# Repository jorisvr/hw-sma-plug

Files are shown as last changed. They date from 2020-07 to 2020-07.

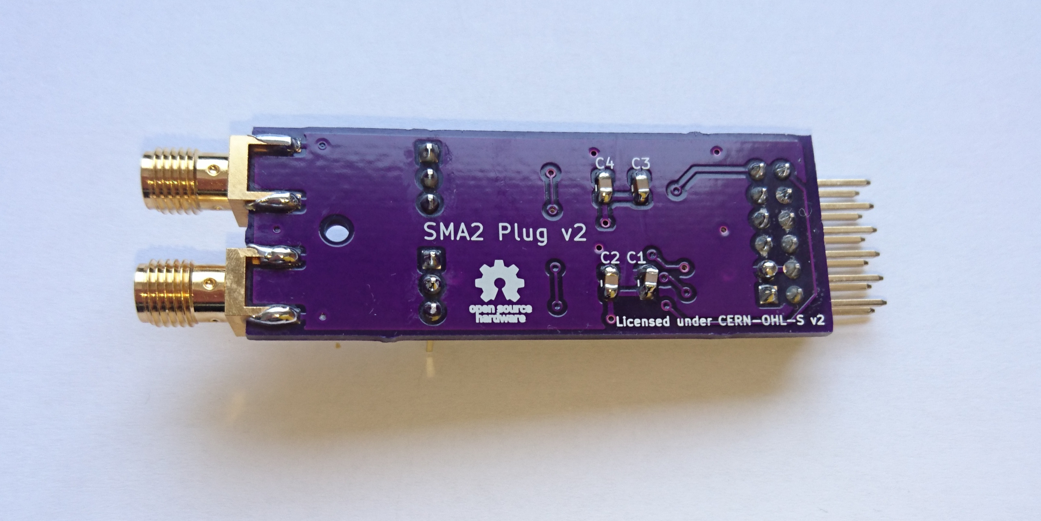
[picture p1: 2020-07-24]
sma2_plug_v2/pictures/assembled_back.jpg

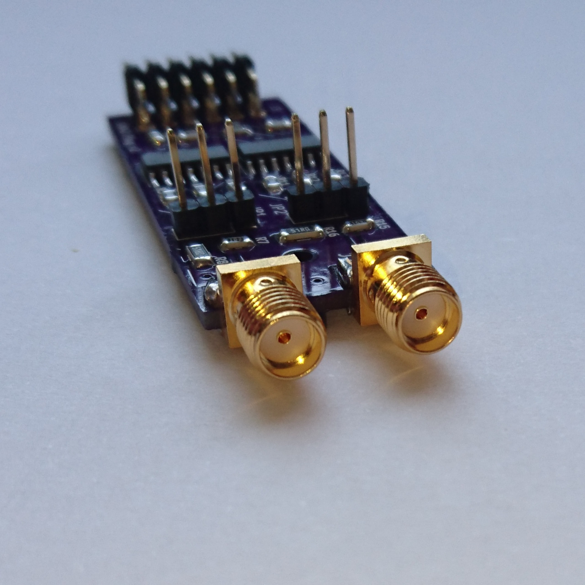
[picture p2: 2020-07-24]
sma2_plug_v2/pictures/assembled_sma_connectors.jpg

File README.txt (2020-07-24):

  SMA2 Plug v2
  ============

The SMA2 Plug is a small printed circuit board (PCB) which can
be used as an extension module to attach coaxial cables to
an FPGA board.

One side of the module has two SMA connectors which can be used
either as digital input or as digital output at TTL level.
The other side of the module has a 2x6 pin header for plugging
into an FPGA board, compatible with the Digilent Pmod specification.

For more details, see the user manual
https://github.com/jorisvr/hw-sma-plug/blob/master/sma2_plug_v2/doc/manual.pdf

The SMA2 Plug is an open hardware design. This repository contains
the complete KiCad design files and design documents for the module.

  Acknowledgements
  ----------------

Many thanks to Sidney Cadot for fundamental ideas about features
and use cases for this module and detailed discussions on the design.

Many thanks to Joris van Zwieten for reviewing the design and
for invaluable advice on SMD soldering.

  License
  -------

Copyright 2020 Joris van Rantwijk

This design documentation describes Open Hardware and is licensed
under the CERN-OHL-S v2.

You may redistribute and modify this documentation and make products
using it under the terms of the CERN-OHL-S v2
(https://cern.ch/cern-ohl).

This documentation is distributed WITHOUT ANY EXPRESS OR IMPLIED
WARRANTY, INCLUDING OF MERCHANTABILITY, SATISFACTORY QUALITY AND
FITNESS FOR A PARTICULAR PURPOSE. Please see the CERN-OHL-S v2
for applicable conditions.

Source location: https://github.com/jorisvr/hw-sma-plug

--

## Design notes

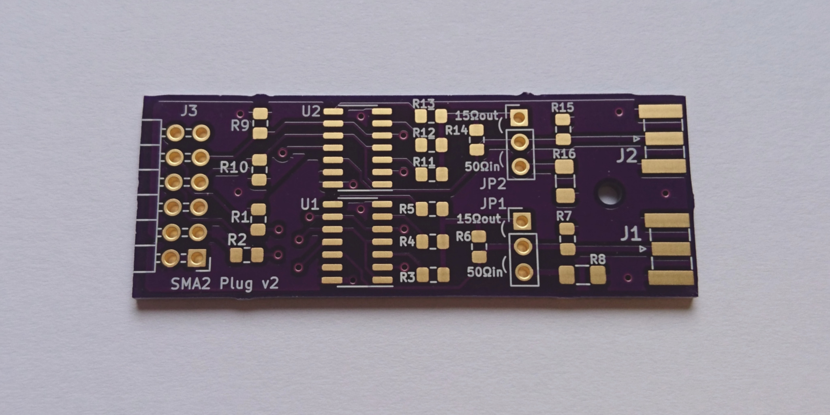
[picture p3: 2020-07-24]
sma2_plug_v2/pictures/pcb_front.jpg

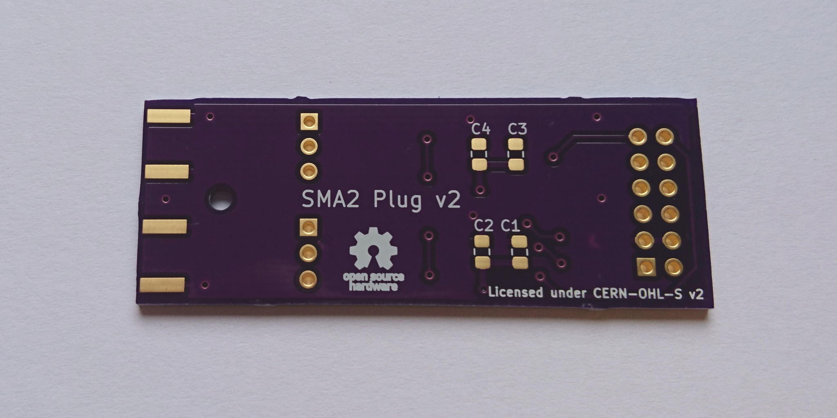
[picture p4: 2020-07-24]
sma2_plug_v2/pictures/pcb_back.jpg

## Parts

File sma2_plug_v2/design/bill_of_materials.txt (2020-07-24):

Bill of materials for SMA2 Plug v2
==================================

  qty  manufacturer + part nr          description                  package   Farnell  Conrad   refdes
  ---  ----------------------          -----------                  --------  -------  -------  ------
    2  Nexperia 74LVC126AD             quad logic buffer 74LVC126   SOIC-14   1631665           U1,U2
    2  KEMET C0805C105K3RAC            capacitor 1uF 25V X7R        0805      1637035  458056   C1,C3
    2  KEMET C0805C104J5RAC            capacitor 100nF 50V X7R      0805      1414663  458028   C2,C4
    6  Bourns CR0805-JW-103ELF         resistor 10 kOhm             0805      2008390  1055517  R1,R2,R7,R9,R10,R15
    8  Multicomp MP000066              resistor 33 Ohm 250 mW       0805      3127836           R3,R4,R5,R6,R11,R12,R13,R14
    2  Bourns CRM1206-FX-51R0ELF       resistor 51 Ohm 500 mW       1206      1865251           R8,R16
    2  Samtec SMA-J-P-H-ST-EM1         SMA connector edge-mount               2856818           J1,J2
    1  Wurth 61301221021               male pin header 2x6 angled   2.54rm    2356197  1898789  J3
    2                                  male pin header 1x3 straight 2.54rm    3226003  1581014  JP1,JP2
    2                                  jumper bridge 2.54rm                   2834673  1303885

NOTE: R8, R16 must be rated for at least 500 mW.
NOTE: R6, R14 must be rated for at least 250 mW.

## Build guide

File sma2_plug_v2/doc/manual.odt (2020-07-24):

# SMA2 Plug v2 User Manual

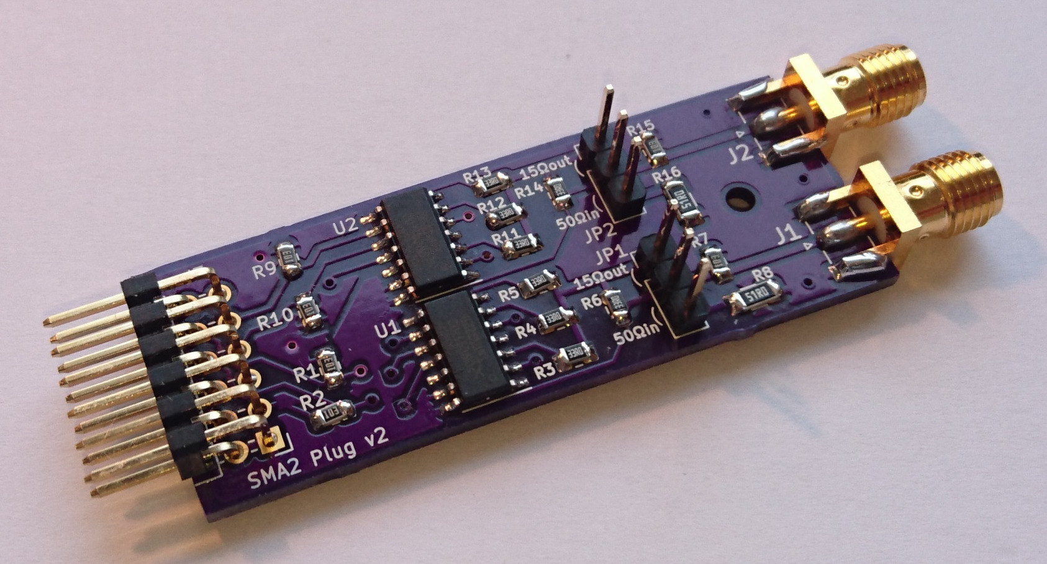
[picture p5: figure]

## Overview

The SMA2 Plug provides an easy way to connect digital TTL signals to an FPGA board via coaxial cables.

One side of the module has two SMA connectors which can each be used either as digital input or as digital output. The other side of the module has a 2x6 pin header which can be plugged into an FPGA board.

The module converts the TTL input level of each SMA connector into a matching IN signal for the FPGA. The module also expects two output signals from the FPGA for each SMA connector: OE (output enable) to enable or disable the output function, and OUT to determines whether the output (if enabled) produces a logic high or logic low level.

Features:

- Two SMA connectors for external digital signals, separately configurable as input or output.
- Useful for connecting TTL control signals or trigger signals to external equipment.
- Signal rate up to 100 Mbit/s.
- Input impedance 10 kOhm or 50 Ohm, configurable via jumper.
- Output 3.3 Volt with 50 Ohm output impedance into high impedance load, or 2.5 Volt with low output impedance into 50 Ohm load, configurable via jumper.
- Compatible with Digilent Pmod specification.

See https://github.com/jorisvr/hw-sma-plug for schematics and design files.

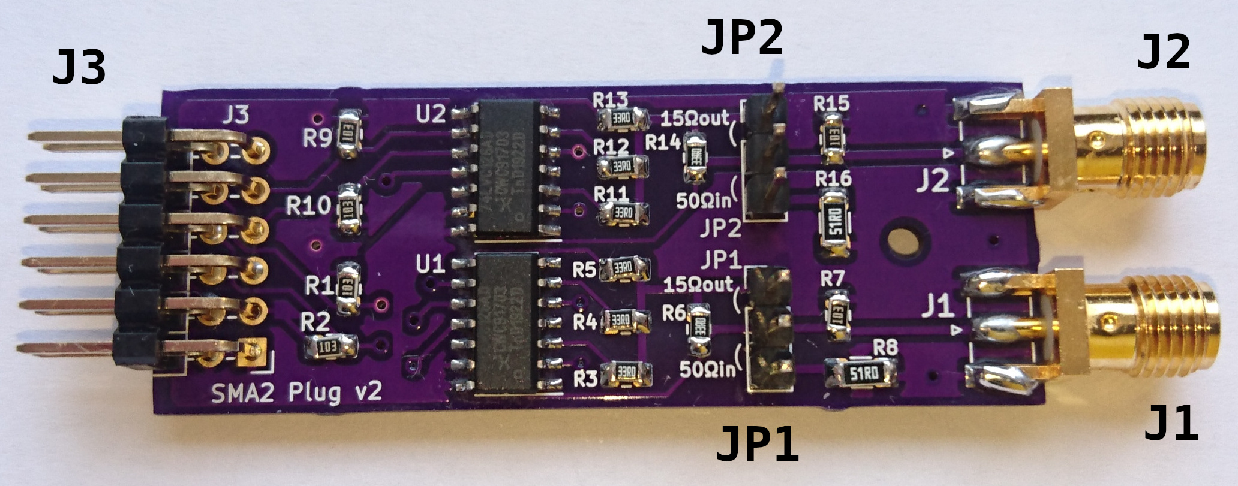
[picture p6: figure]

## Connectors

Label | Type | Description
J1 | SMA | Digital input/output channel 1
J2 | SMA | Digital input/output channel 2
J3 | 2x6 pin header | Connection to FPGA board

Table 1: Connectors

Connector J3 is compatible with the Digilent Pmod specification v1.2.0

(see https://reference.digilentinc.com/reference/pmod/start). This means the module will work when plugged into a dual-row Pmod connector as present on many Digilent FPGA boards.

Figure 1: Pin numbers of Pmod connector on host FPGA board and SMA Plug module

host Pmod socket

host board edge

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
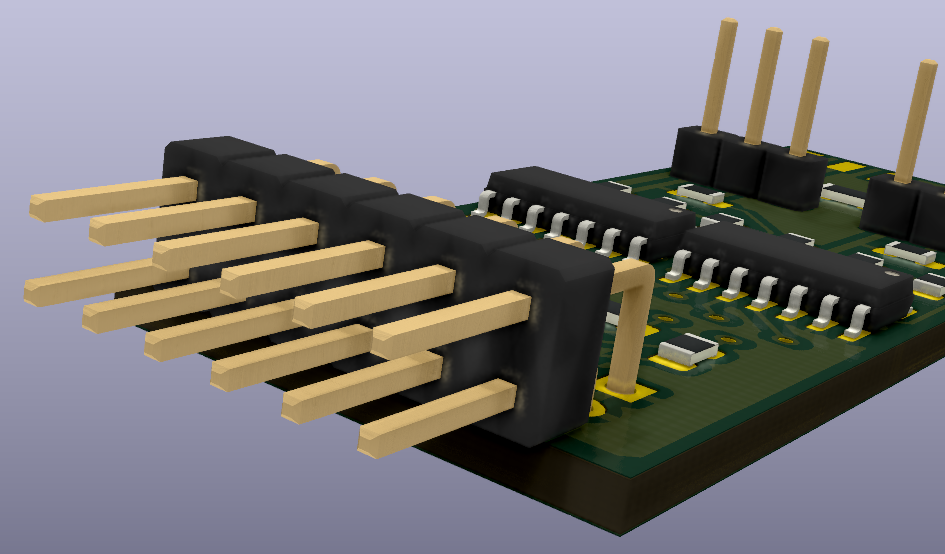
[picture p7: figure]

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
The pin functions of connector J3 match Pmod interface type 1A (GPIO).

The pin assignments are as follows:

Pin nr | Name | In/out | Function
1 | IN2 | FPGA input | Input signal from J2.
2 | OUT2 | FPGA output | Output signal for J2.
3 | OE2 | FPGA output | High to enable output via J2; low to disable output via J2.
4 | | | not connected
5 | GND | | 0 V ground
6 | 3V3 | | +3.3 V power supply from FPGA board
7 | IN1 | FPGA input | Input signal from J1.
8 | OUT1 | FPGA output | Output signal for J1.
9 | OE1 | FPGA output | High to enable output via J1; low to disable output via J1.
10 | | | not connected
11 | GND | | 0 V ground
12 | 3V3 | | +3.3 V power supply from FPGA board

Table 2: Connector J3 pin assignments

Note: These pin number assignments are based on the Digilent Pmod specification. The schematic of the SMA2 Plug v2 uses different pin numbers internally.

## Jumpers

Each of the two SMA ports has a 3-pin jumper which is used to choose between 3 modes of operation for that port. The jumper settings are as follows:

Jumper not connected

1

2

3

15Ω out

50Ω in

This is the best setting to use in most cases.

The input function receives a TTL signal from an external device. The SMA Plug input has 10 kΩ termination. The external device is expected to provide 50 Ω source termination to avoid reflections in the cable.

The output function drives a 3.3 V TTL signal to an external device with high input impedance. The output has 50 Ω series termination to avoid reflections in the coax cable. The external device must have high input impedance (at least 500 Ω) to ensure that the output meets the TTL threshold.

Input function: 10 kΩ input impedance.

Input threshold: logic low level max 0.8 V, logic high level min 2.0 V.

Output function: 50 Ω output resistance.

Output levels: 0.0 V to 3.2 V into high-impedance load.

Jumper connected from pin 1 to pin 2

1

2

3

15Ω out

50Ω in

This mode is suitable for driving a 2.5 V TTL output signal to an external device with 50 Ω input impedance.

The jumper reduces the output resistance of the SMA Plug to 15 Ω to make it strong enough to drive a 50 Ω load. This only works well if the coax cable ends in 50 Ω termination at the external device, otherwise reflections may occur.

Input function: 10 kΩ input impedance.

Input threshold: logic low level max 0.8 V, logic high level min 2.0 V.

Output function: 15 Ω output resistance.

Output levels: 0.0 V to 2.5 V into 50 Ω load.

Jumper connected from pin 2 to pin 3

1

2

3

15Ω out

50Ω in

This mode is suitable for TTL input from an external device which is designed to drive a 50 Ω load. The jumper connects a 50 Ω load resistor between the SMA port and ground to terminate the coax cable.

In this mode the input voltage must stay below 3.6 V to prevent overheating of the load resistor.

Input function: 50 Ohm input impedance.

Input threshold: logic low level max 0.8 V, logic high level min 2.0 V.

Output function: not usable (keep OEn = '0').

## Specifications

Physical specifications

Board dimensions: | 54.4 x 20.4 mm

Damage limits

Input voltage limits: | minimum | −0.5 V
| maximum (10 kΩ input impedance) | +5.5 V
| maximum (50 Ω input impedance) | +3.6 V
Output load: | minimum load resistance | 30 Ω

Exceeding these limits may damage the SMA Plug.

Short-circuiting the SMA connector with output enabled may damage the SMA Plug.

Voltage levels

Input thresholds: | logic low level, maximum input voltage | 0.8 V
| logic high level, minimum input voltage | 2.0 V
Output levels: (typical) | logic low output level | 0.0 V
| logic high output level (50 Ω output resistance, > 1 kΩ load) | 3.2 V
| logic high output level (15 Ω output resistance, 50 Ω load) | 2.5 V

Power consumption

Supply current: (typical) | both outputs disabled | 1 mA
| both outputs enabled, logic high output, 15 Ω output resistance, 50 Ω load | 100 mA

Copyright 2020 Joris van Rantwijk

This manual describes Open Hardware and is licensed under the CERN-OHL-S v2.

You may redistribute and modify this documentation and make products using it under the terms of the CERN-OHL-S v2 (https://cern.ch/cern-ohl).

This documentation is distributed WITHOUT ANY EXPRESS OR IMPLIED WARRANTY, INCLUDING OF MERCHANTABILITY, SATISFACTORY QUALITY AND FITNESS FOR A PARTICULAR PURPOSE. Please see the CERN-OHL-S v2 for applicable conditions.

Source location: https://github.com/jorisvr/hw-sma-plug

SMA2 Plug v2 User Manual 20200718 4 / 4

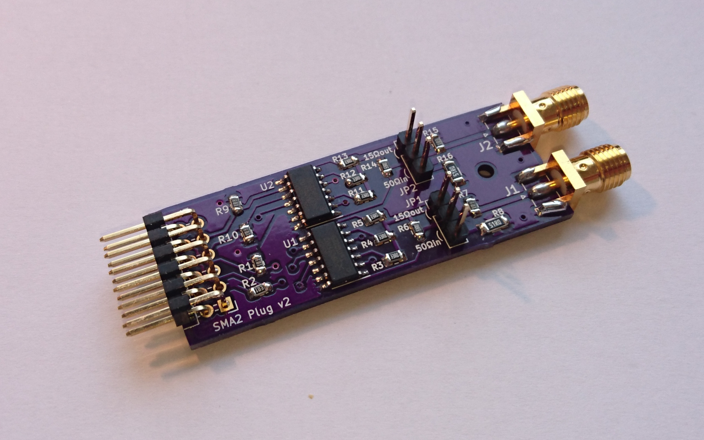
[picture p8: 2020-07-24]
sma2_plug_v2/pictures/assembled_front_angle.jpg

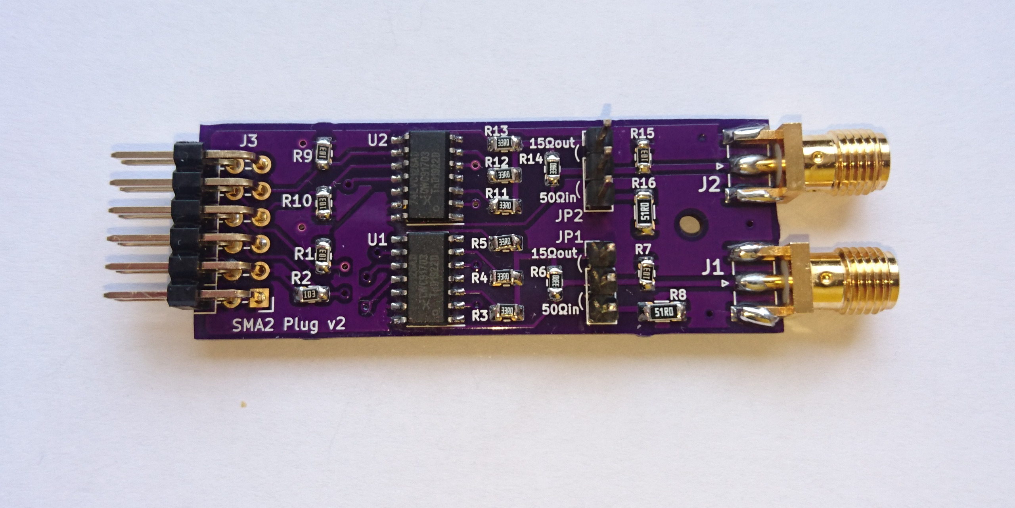
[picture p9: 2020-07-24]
sma2_plug_v2/pictures/assembled_front.jpg

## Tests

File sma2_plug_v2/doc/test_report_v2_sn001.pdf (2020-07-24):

## Test Report: SMA2 Plug v2 nr 001

Design: | SMA2 Plug v2
Serial number: | 001
Date tested: | 2020-07-23
Tested by: | joris
Report date: | 2020-07-23

## Pmod pinout

This test report refers to Pmod pins according to the non-standard pin number assignments used in the Digilent Pmod specification.

Looking away from the peripheral board, into the Pmod connector on the host board, the pin numbers are as follows:

The SMA2_Plug_v2 board uses the pinout of Digilent Pmod Interface Type 1 (GPIO).

Pin nr | function | in/out
1 | IN2 | output from peripheral
2 | OUT2 | input to peripheral
3 | OE2 | input to peripheral
7 | IN1 | output from peripheral
8 | OUT1 | input to peripheral
9 | OE1 | input to peripheral
4, 10 | not connected
5, 11 | GND
6, 12 | +3.3 V
Test Report - SMA2_Plug_v2 nr 001 | 1
6 | 5 | 4 | 3 | 2 | 1
12 | 11 | 10 | 9 | 8 | 7

host Pmod socket

host board edge

### Sanity checks

1.1. Remove jumpers JP1 and JP2 (to select 50 Ω output resistance).
1.2. Use a multimeter to measure the resistance between Pmod pins 5 and 11.
1.3. Use a multimeter to measure the resistance between Pmod pins 6 and 12.
Measurement | Expected | Result
1.2. Pmod pin 5 to pin 11 | < 0.1 Ω | 0.0 Ω OK
1.3. Pmod pin 6 to pin 12 | < 0.1 Ω | 0.0 Ω OK
1.4. Use a multimeter to measure the resistance between Pmod pin 5 and the shell of SMA connector J1.
1.5. Use a multimeter to measure the resistance between Pmod pin 5 and the shell of SMA connector J2.
Measurement | Expected | Result
1.3. Pmod pin 5 to J1 shell | < 0.1 Ω | 0.0 Ω OK
1.4. Pmod pin 5 to J2 shell | < 0.1 Ω | 0.0 Ω OK
1.6. Set a DC voltage source to +3.3 V, limited to 100 mA.
Connect the negative supply terminal to pin 5.
Connect the positive supply terminal to pin 6.
Leave the other Pmod pins unconnected.
1.7. Use a multimeter to measure the supply voltage.
1.8. Use a multimeter to measure the supply current.
1.9. Additionally connect Pmod pin 9 (OE1) to +3.3 V and measure the supply current.
1.10. Connect both Pmod pin 8 (OUT1) and Pmod pin 9 (OE1) to +3.3 V and measure the supply current.
1.11. Disconnect Pmod pins 8 and 9.
Connect Pmod pin 3 (OE2) to +3.3 V and measure the supply current.
1.12. Connect both Pmod pin 2 (OUT2) and Pmod pin 3 (OE2) to +3.3 V and measure the supply current.
Measurement | Expected | Result
1.7. Supply voltage | min 3.2 V, max 3.4 V | 3.30 V OK
1.8. Supply current | < 1 mA | 0.0 mA OK
1.9. Supply current, OE1=+3.3V | < 3 mA | 0.3 mA OK
1.10. Supply current, OE1=OUT1=+3.3V | < 3 mA | 1.0 mA OK
1.11. Supply current, OE2=+3.3V | < 3 mA | 0.3 mA OK
1.12. Supply current, OE2=OUT2=+3.3V | < 3 mA | 1.0 mA OK
1.13. Disconnect Pmod pins 2 and 3. Disconnect the power supply.
Test Report - SMA2_Plug_v2 nr 001 | 2

### Functional test

2.1. Remove jumpers JP1 and JP2 (to select 50 Ω output resistance).
Attach the SMA2 Plug to a Pmod type 1 (GPIO) connector on a suitable Digilent host board (for example Basys or Atlys).
Make sure the Pmod connector on the host board is configured for 3.3 Volt operation.
2.2. Program the host board to drive logic '0' to OUT1, OE1, OUT2, OE2.
2.3. Use the host board to read the logic levels from IN1, IN2.
2.4. Connect a +3.3 Volt input signal to SMA connector J1.
Use the host board to read the logic levels from IN1, IN2.
2.5. Disconnect the input signal from J1.
Connect a +3.3 Volt input signal to SMA connector J2.
Use the host board to read the logic levels from IN1, IN2.
Measurement | Expected | Result
2.3. Input not connected | IN1=0, IN2=0 | OK
2.4. J1 = 3.3 V | IN1=1, IN2=0 | OK
2.5. J2 = 3.3 V | IN1=0, IN2=1 | OK
2.6. Disconnect the input signal from J2.
Connect a multimeter to measure the output voltage from J1.
Use the host board to drive the following logic patterns and measure the output voltage from J1 for each pattern.
Measurement | Expected | Result
OUT1=0, OE1=0, OUT2=0, OE2=0 | J1 ≥ 0.0 V, J1 < 0.2 V | 0.00 V OK
OUT1=0, OE1=0, OUT2=1, OE2=1 | J1 ≥ 0.0 V, J1 < 0.2 V | 0.00 V OK
OUT1=1, OE1=0, OUT2=0, OE2=0 | J1 ≥ 0.0 V, J1 < 0.2 V | 0.00 V OK
OUT1=0, OE1=1, OUT2=0, OE2=0 | J1 ≥ 0.0 V, J1 < 0.2 V | 0.00 V OK
OUT1=1, OE1=1, OUT2=0, OE2=0 | J1 > 3.1 V, J1 < 3.4 V | 3.26 V OK
2.7. Disconnect the input signal from J1.
Connect a multimeter to measure the output voltage from J2.
Use the host board to drive the following logic patterns and measure the output voltage from J2 for each pattern.
Measurement | Expected | Result
OUT1=0, OE1=0, OUT2=0, OE2=0 | J2 ≥ 0.0 V, J2 < 0.2 V | 0.00 V OK
OUT1=1, OE1=1, OUT2=0, OE2=0 | J2 ≥ 0.0 V, J2 < 0.2 V | 0.00 V OK
OUT1=0, OE1=0, OUT2=1, OE2=0 | J2 ≥ 0.0 V, J2 < 0.2 V | 0.00 V OK
OUT1=0, OE1=0, OUT2=0, OE2=1 | J2 ≥ 0.0 V, J2 < 0.2 V | 0.00 V OK
OUT1=0, OE1=0, OUT2=1, OE2=1 | J2 > 3.1 V, J2 < 3.4 V | 3.26 V OK
Test Report - SMA2_Plug_v2 nr 001 | 3

2.8. Use the host board to drive OE1 = 1, OUT1 = 1, OE2 = 1, OUT2 = 1.
Use a multimeter to measure the output voltage from J1 and J2.
Then connect a 50 Ohm resistor in parallel to the multimeter (use an SMA T-joint). Again measure the output voltage from J1 and J2.
Measurement | Expected | Result J1 | Result J2
high output level, high-Z | > 3.1 V, < 3.4 V | 3.257 V | 3.257 V
high output level, 50 Ohm | > 1.5 V, < 1.7 V | 1.648 V | 1.656 V
2.9. Place jumpers JP1 and JP2 in the "15 Ω output" position.
Use the host board to drive OE1 = 1, OUT1 = 1, OE2 = 1, OUT2 = 1.
Use a multimeter to measure the output voltage from J1 and J2.
Then connect a 50 Ohm resistor in parallel to the multimeter (use an SMA T-joint). Again measure the output voltage from J1 and J2.
Measurement | Expected | Result J1 | Result J2
high output level, high-Z | > 3.1 V, < 3.4 V | 3.268 V | 3.268 V
high output level, 50 Ohm | > 2.4 V, < 2.6 V | 2.474 V | 2.480 V
2.10. Remove jumpers JP1 and JP2.
Use the host board to drive OE1 = 0, OUT1 = 0, OE2 = 0, OUT2 = 0.

Use a multimeter to measure the input resistance of J1 and J2.
Then place jumpers JP1 and JP2 in the "50 Ω input" position.
Again measure the input resistance of J1 and J2.
Measurement | Expected | Result J1 | Result J2
input resistance, high-Z | > 9 kΩ , < 11 kΩ | 10.00 kΩ | 10.00 kΩ
input resistance, 50 Ohm | > 48 Ω, < 52 Ω | 50.8 Ω | 50.8 Ω
Test Report - SMA2_Plug_v2 nr 001 | 4

### Input performance test

3.1. Remove jumpers JP1 and JP2.
Attach the SMA2 Plug to a Pmod type 1 (GPIO) connector on a suitable Digilent host board (for example Basys or Atlys).
3.2. Connect a signal generator to SMA connector J1.
Usa an SMA T-joint to also measure the voltage with a multimeter.

Configure the signal generator for high-Z load.
Set the signal generator to 0.0 Volt DC output.
Use the host board to check that the IN1 logic level is '0'.
3.3. Slowly tune up the DC output voltage from 0.0 Volt to +3.3 Volt.
Verify that the multimeter follows the configured output voltage.

While tuning up the input voltage, monitor the IN1 logic level with the host board. Note the voltage where the IN1 logic level changes from '0' to '1'.
Then tune down the input voltage and note where IN1 changes from '1' to '0'.
Measurement | Expected | Result J1 | Result J2
3.2. Jx = 0.0 V | INx=0 | OK | OK
3.3. 0-to-1 threshold | > 0.8 V, < 2.0 V | 1.70 V | 1.69 V
3.3. 1-to-0 threshold | > 0.8 V, < 2.0 V | 1.64 V | 1.64 V
3.4. Set the signal generator to +3.3 Volt DC output.
Check that the multimeter shows +3.3 Volt.
3.5. Place jumper JP1 in the "50 Ω input" position. Configure the signal generator for 50 Ohm load. Set the signal generator to +3.3 Volt DC output.
Check that the multimeter shows +3.3 Volt.
Check that the IN1 logic level is '1'.
Measurement | Expected | Result J1 | Result J2
3.4. voltage at +3.3V, high-Z | > 3.2 V, < 3.4 V | 3.273 V | 3.274 V
3.5. voltage at +3.3 V, 50 Ohm | > 3.2 V, < 3.4 V | 3.322 V | 3.324 V
3.5. INx at +3.3 V, 50 Ohm | INx=1 | OK | OK
Test Report - SMA2_Plug_v2 nr 001 | 5

3.6. Remove the T-joint and multimeter.
Connect the signal generator directly to J1, using a coax cable of at least 10 m length.

Leave jumper JP1 in the "50 Ω input" position.
Configure the signal generator for 50 Ohm load.
Set the signal generator to square wave output, 1 MHz, 50% duty cycle, 0.0 Volt to +2.5 Volt (2.5 Vpp with +1.25 V offset).

Use the host board to sample the IN1 signal at a sample rate of 500 MS/s.
Record the min/max/avg pulse high duration and the min/max/avg pulse low duration.

Calculate the square wave frequency from the average pulse durations:
freq = 1 / (avg_pulse_low + avg_pulse_high)

Calculate the duty cycle from the average pulse lengths:
duty_cycle = avg_pulse_high / (avg_pulse_low + avg_pulse_high)

Calculate the peak-to-peak jitter:
jitter = max(max_pulse_high - min_pulse_high, max_pulse_low - min_pulse_low)
Measurement | Expected | Result J1 | Result J2
pulse low: min/max/avg (ns) | | 500 / 504 / 501.9 | 500 / 504 / 502.0
pulse high: min/max/avg (ns) | | 496 / 500 / 498.1 | 496 / 500 / 498.0
frequency | 1 MHz +/- 0.01 MHz | 1.000 MHz | 1.000 MHz
duty cycle | > 49%, < 51% | 50.2 % | 50.2 %
jitter | < 5 ns | 4 ns | 4 ns
3.7. Configure the signal generator for high-Z load.
Set the signal generator to 1 MHz square wave output, 0.0 Volt to +2.5 Volt. Remove jumper JP1.
Repeat the measurements of 3.6., this time in high-Z configuration.
Measurement | Expected | Result J1 | Result J2
pulse low: min/max/avg (ns) | | 500 / 504 / 502.0 | 500 / 504 / 502.0
pulse high: min/max/avg (ns) | | 496 / 500 / 498.0 | 496 / 500 / 498.0
frequency | 1 MHz +/- 0.01 MHz | 1.000 MHz | 1.000 MHz
duty cycle | > 49%, < 51% | 50.2 % | 50.2 %
jitter | < 5ns | 4 ns | 4 ns
3.8. Use the host board to generate cross-talk on the other channel:
Set OE2 = '1' and send a random sequence of bits to OUT2 at 100 Mbit/s. Repeat the jitter measurements of step 3.7 under these conditions.
Measurement | Expected | Result J1 | Result J2
jitter | < 5ns | 4 ns | 4 ns
3.9. Disconnect the signal generator from J1.
Repeat steps 3.2. to 3.8. but this time use input J2, jumper J2, monitor IN2 and generate cross-talk through OE1, OUT1.
Test Report - SMA2_Plug_v2 nr 001 | 6

### Output performance test

4.1. Remove jumpers JP1 and JP2 to select 50 Ω output resistance.
Attach the SMA2 Plug to a Pmod type 1 (GPIO) connector on a suitable Digilent host board (for example Basys or Atlys).
4.2. Connect SMA connector J1 to an oscilloscope with at least 200 MHz analog bandwidth. Use a coax cable of at most 2 m length.
Set the scope to DC coupling, 1 MOhm input impedance, full bandwidth.
4.3. Set the host board to drive OE1 = 1, OUT1 = 0, OE2 = 0, OUT2 = 0.
Analyze the J1 waveform on the scope.
It should be a DC voltage. Note mean level and noise.
4.4. Set the host board to drive OE1 = 1, OUT1 = 0, OE2 = 1 and send a random sequence of bits to OUT2 at 100 Mbit/s.
Analyze the J1 noise on the scope.
4.5. Set the host board to drive OE1 = 1, OUT1 = 1, OE2 = 0, OUT2 = 0.
Analyze the J1 waveform on the scope.
It should be a DC voltage. Note mean level and noise.
4.6. Set the host board to drive OE1 = 1, OUT1 = 1, OE2 = 1 and send a random sequence of bits to OUT2 at 100 Mbit/s.
Analyze the J1 noise on the scope.
Measurement | Expected | Result J1 | Result J2
4.3. mean output signal | ≥ 0.0 V, < 0.2 V | 0.0 V
4.3. noise (other channel silent) | < 0.2 V pp | 0.03 V pp
4.4. noise (other channel busy) | < 0.2 V pp | 0.03 V pp
4.5. mean output signal | > 3.1 V, < 3.4 V | 3.24 V
4.5. noise (other channel silent) | < 0.2 V pp | 0.02 V pp
4.6. noise (other channel busy) | < 0.2 V pp | 0.02 V pp
Test Report - SMA2_Plug_v2 nr 001 | 7

4.7. Set the host board to drive OE1 = 1, OE2 = 0, OUT2 = 0 and drive a 1 MHz square wave to OUT1.
Analyze the J1 waveform on the oscilloscope.
It should be a 1 MHz square wave. Note the mean high and low levels.
Note the rise time and fall time. Note the overshoot.
Note the interval between successive rising edges.
Note the peak-to-peak jitter: the interval between longest and shortest period (use the persistent display mode of the scope).
Measurement | Expected | Result J1 | Result J2
mean low level | > −0.1 V, < 0.2 V | 0.02 V
mean high level | > 3.1 V, < 3.4 V | 3.22 V
rise time from 0.8 V to 2.0 V | < 5 ns | < 1 ns
fall time from 2.0 V to 0.8 V | < 5 ns | < 1 ns
rising edge overshoot | < 0.2 V | 0.20 V
falling edge overshoot | < 0.2 V | 0.16 V
no ringing (repeated overshoot) | | OK
period | 1 μs ± 10 ns | 1.000 us
jitter | < 5 ns pp | < 1 ns pp

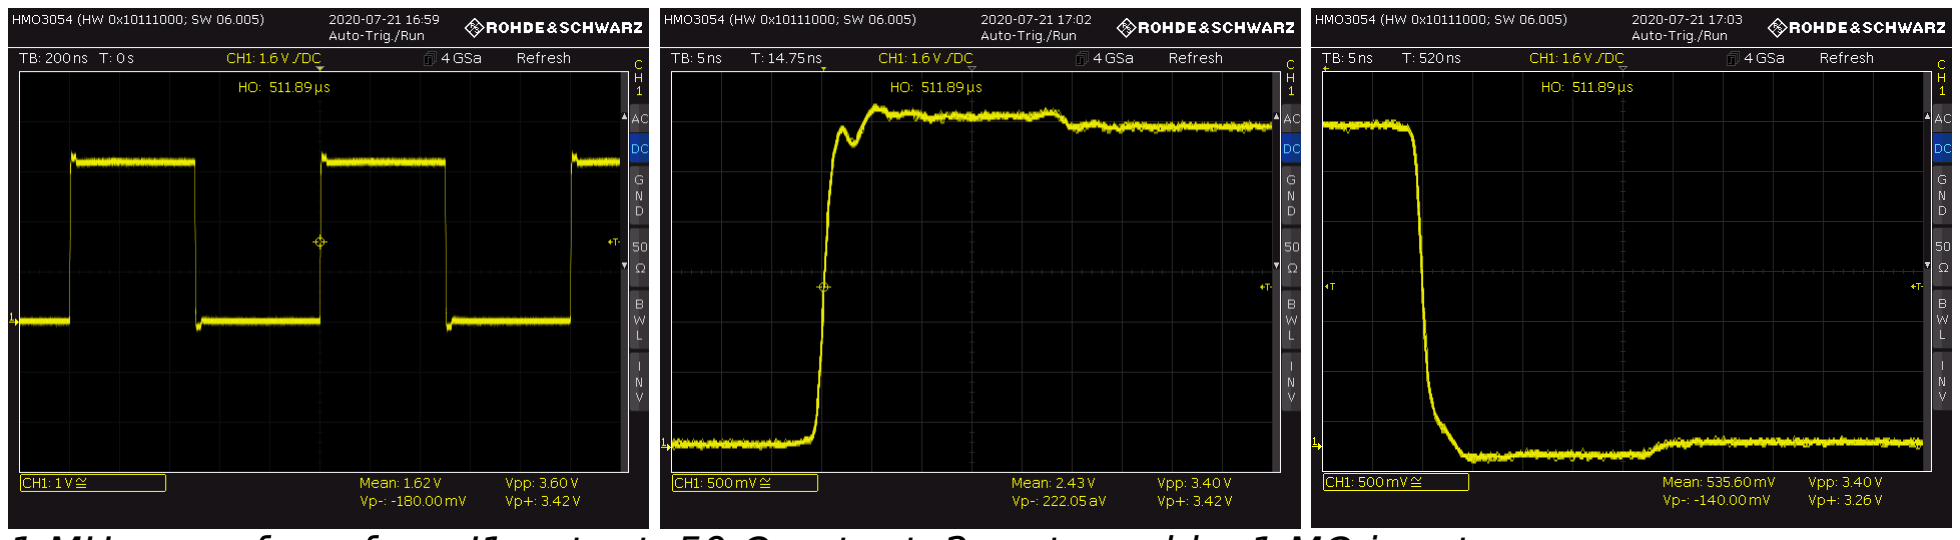
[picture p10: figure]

1 MHz waveform from J1 output, 50 Ω output, 2 meter cable, 1 MΩ input on scope

4.8. Reconnect the oscilloscope to J1 using a coax cable of at least 10 m length. Repeat the measurement of 4.7.
Measurement | Expected | Result J1 | Result J2
mean low level | > −0.1 V, < 0.2 V | 0.02 V | 0.03 V
mean high level | > 3.1 V, < 3.4 V | 3.23 V | 3.22 V
rise time from 0.8 V to 2.0 V | < 5 ns | 1 ns | 1 ns
fall time from 2.0 V to 0.8 V | < 5 ns | < 2 ns | < 2 ns
rising edge overshoot | < 0.2 V | 0.18 V | 0.18 V
falling edge overshoot | < 0.2 V | 0.17 V | 0.18 V
no ringing (repeated overshoot) | | OK | OK
jitter | < 5 ns pp | < 1 ns pp | < 1 ns pp
Test Report - SMA2_Plug_v2 nr 001 | 8

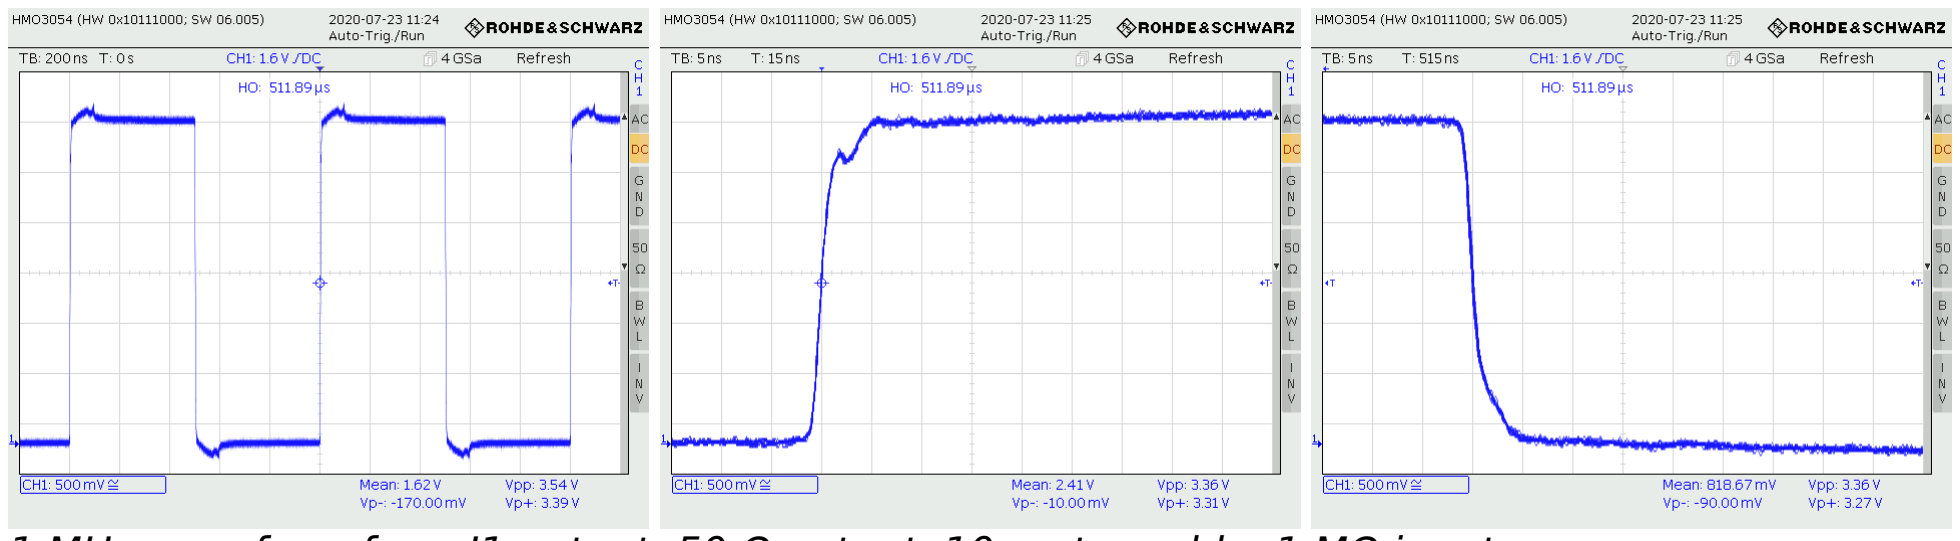
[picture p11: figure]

1 MHz waveform from J1 output, 50 Ω output, 10 meter cable, 1 MΩ input on scope

4.9. Set the host board to drive OE = 1, OE2 = 1, drive a 1 MHz square wave to OUT1, and send a random sequence of bits to OUT2 at 100 Mbit/s.
Check the jitter on the oscilloscope.
Measurement | Expected | Result J1 | Result J2
jitter | < 5 ns pp | < 1 ns pp | < 1 ns pp
4.10. Set the host board to drive OE1 = 1, OE2 = 1 and send independent random sequences of bits to OUT1 and OUT2 at 100 Mbit/s.
Set the oscilloscope time base to 5 ns.
Trigger on rising edge with trigger level +1.4 V.
Enable persistence and collect at least 10000 traces.

Analyze the resulting eye pattern. Note the duration of the interval where the signal is either below +0.8 V or above +2.0 V in each collected trace.

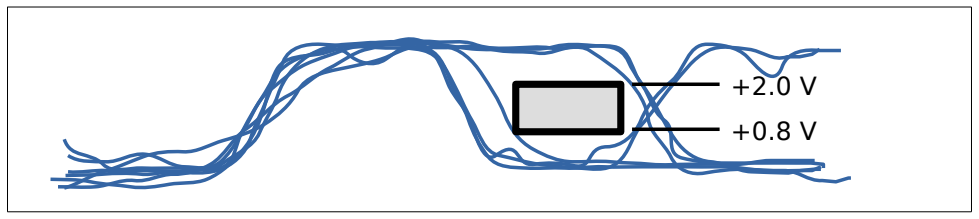
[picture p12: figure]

Measurement | Expected | Result J1 | Result J2
eye pattern clear duration | > 5 ns | 7 ns | 7 ns

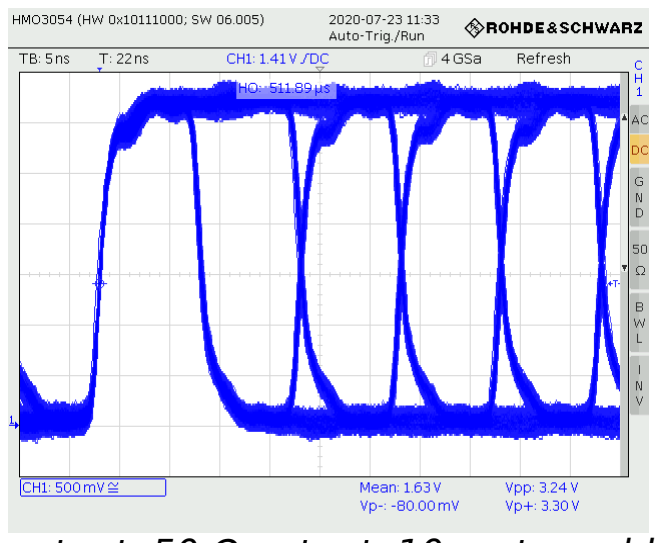
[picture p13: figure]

100 Mbit random data from J1 output, 50 Ω output, 10 meter cable, 1 MΩ input on scope

Test Report - SMA2_Plug_v2 nr 001 | 9

4.11. Switch the oscilloscope to 50 Ω input.
Place jumpers JP1 and JP2 in the "15 Ω output" position.
Repeat the measurements of 4.8, 4.9 and 4.10.

1 MHz square signal, other channel silent, 10 m cable, 15 Ω output, 50 Ω scope:
Measurement | Expected | Result J1 | Result J2
mean low level | > −0.1 V, < 0.2 V | 0.02 V | 0.03 V
mean high level | > 2.4 V, < 2.6 V | 2.42 V | 2.42 V
rise time from 0.8 V to 2.0 V | < 5 ns | 1 ns | 1 ns
fall time from 2.0 V to 0.8 V | < 5 ns | 1 ns | 1 ns
rising edge overshoot | < 0.2 V | 0.0 V | 0.0 V
falling edge overshoot | < 0.2 V | 0.0 V | 0.0 V
no ringing (repeated overshoot) | | OK | OK
jitter | < 5 ns pp | < 1 ns pp | < 1 ns pp

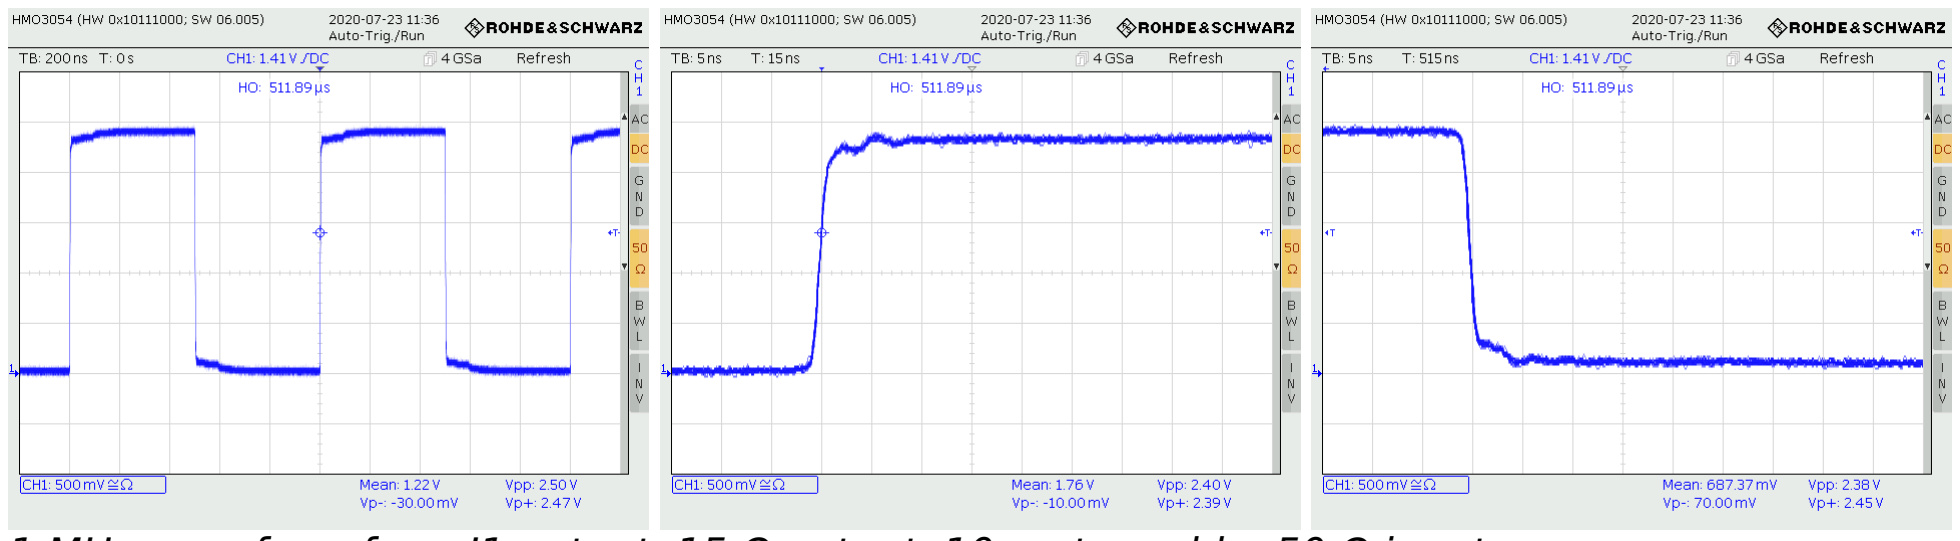
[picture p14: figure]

1 MHz waveform from J1 output, 15 Ω output, 10 meter cable, 50 Ω input on scope

1 MHz square signal, other channel busy, 10 m cable, 15 Ω output, 50 Ω scope:
Measurement | Expected | Result J1 | Result J2
jitter | < 5 ns pp | < 1 ns pp | < 1 ns pp

random 100 Mbit/s signal on both channels, 10 m cable, 15 Ω output, 50 Ω scope, eye pattern:
Measurement | Expected | Result J1 | Result J2
eye pattern clear duration | > 5 ns | 7 ns | 8 ns

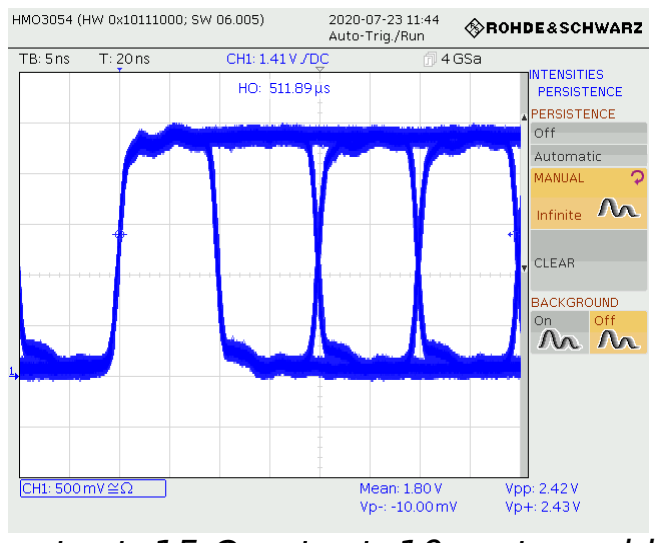
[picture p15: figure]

100 Mbit random data from J1 output, 15 Ω output, 10 meter cable, 50 Ω input on scope

4.12. Disconnect the oscilloscope from J1. Repeat steps 4.3 to 4.11, but this time connect the oscilloscope to J2 and switch the roles of OE1,OUT1 with OE2,OUT2.
Test Report - SMA2_Plug_v2 nr 001 | 10

### Output jitter

5.1. Remove jumpers JP1 and JP2 to select 50 Ω output resistance.
Attach the SMA2 Plug to a Pmod type 1 (GPIO) connector on a suitable Digilent host board (for example Basys or Atlys).
5.2. Use a coax cable of at least 10 m length to connect SMA connector J1 to the input of a frequency counter (Pendulum CNT-91 or similar).
Configure the timer input to DC coupling, high input impedance.
Trigger on rising edge at +1.6 V.
5.3. Set the host board to drive OE1 = 1, OE2 = 0, OUT2 = 0 and drive a 1 MHz square wave to OUT1.

Set Settings, measurement time = 10 seconds.
Use function Freq A to measure frequency.
Set Settings, Stat, N = 10000.
Use function Period, Single, A and enable Stat/Plot to measure jitter.
Measurement | Expected | Result J1 | Result J2
average frequency | 1 MHz ± 0.001 MHz | 1.0000 MHz | 1.0000 MHz
jitter peak-to-peak | < 1 ns pp | 0.36 ns pp | 0.36 ns pp
jitter RMS | < 0.3 ns rms | 47 ps rms | 48 ps rms
5.4. Set the host board to drive OE = 1, OE2 = 1, drive a 1 MHz square wave to OUT1, and send a random sequence of bits to OUT2 at 100 Mbit/s.
Measure jitter under these conditions.
Measurement | Expected | Result J1 | Result J2
jitter peak-to-peak | < 1 ns pp | 0.48 ns pp | 0.50 ns pp
jitter RMS | < 0.3 ns rms | 57 ps rms | 58 ps rms
5.5. Place jumpers JP1 and JP2 in the "15 Ω output" position.
Reconfigure the timer input to 50 Ω input impedance.
Repeat measurement steps 5.3 and 5.4.
Measurement | Expected | Result J1 | Result J2
average frequency | 1 MHz ± 0.001 MHz | 1.0000 MHz | 1.0000 MHz
jitter peak-to-peak (other channel silent) | < 1 ns pp | 0.37 ns pp | 0.42 ns pp
jitter RMS (other channel silent) | < 0.3 ns rms | 47 ps rms | 48 ps rms
jitter peak-to-peak (other channel busy) | < 1 ns pp | 0.47 ns pp | 0.43 ns pp
jitter RMS (other channel busy) | < 0.3 ns rms | 56 ns rms | 56 ps rms
5.6. Disconnect J1. Connect J2 to the frequency counter and repeat steps 5.3 and 5.5 but switch the roles of OE1,OUT1 with OE2,OUT2.
Test Report - SMA2_Plug_v2 nr 001 | 11

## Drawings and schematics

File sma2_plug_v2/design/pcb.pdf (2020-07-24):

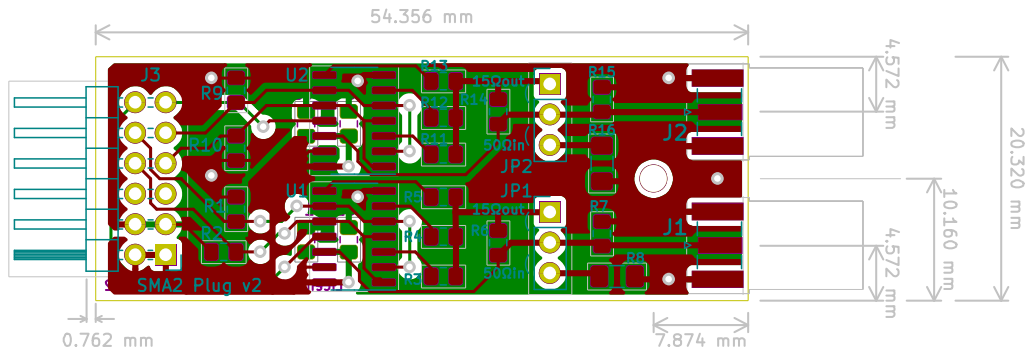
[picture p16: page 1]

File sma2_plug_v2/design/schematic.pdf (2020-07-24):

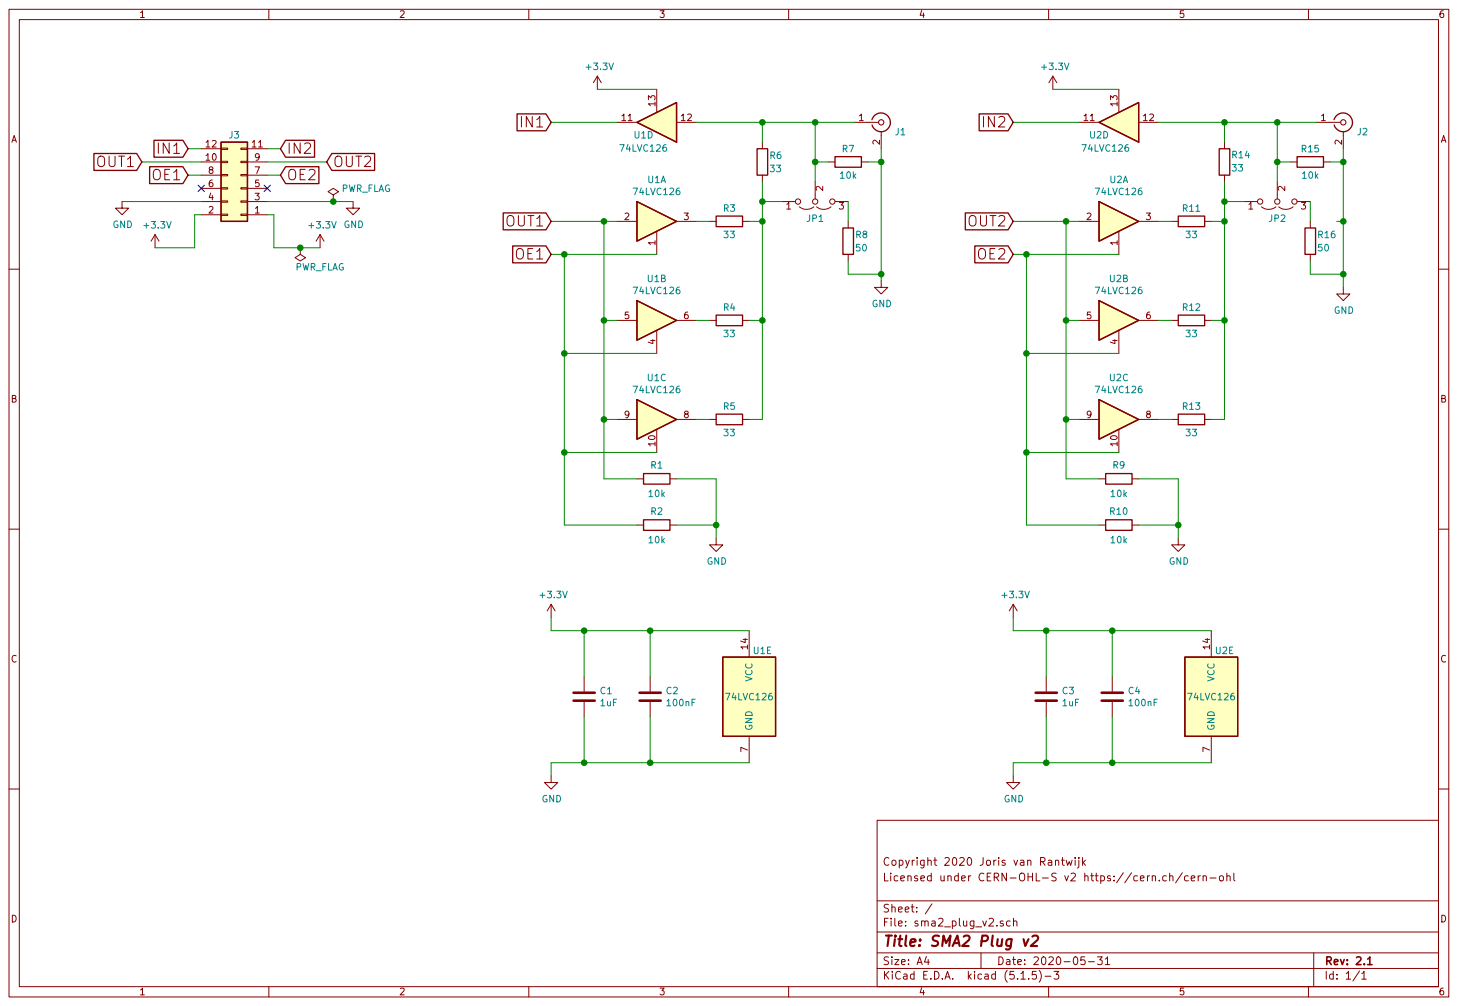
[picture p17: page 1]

Copyright 2020 Joris van Rantwijk
File: sma2_plug_v2.sch Sheet: / Licensed under CERN-OHL-S v2 https://cern.ch/cern-ohl

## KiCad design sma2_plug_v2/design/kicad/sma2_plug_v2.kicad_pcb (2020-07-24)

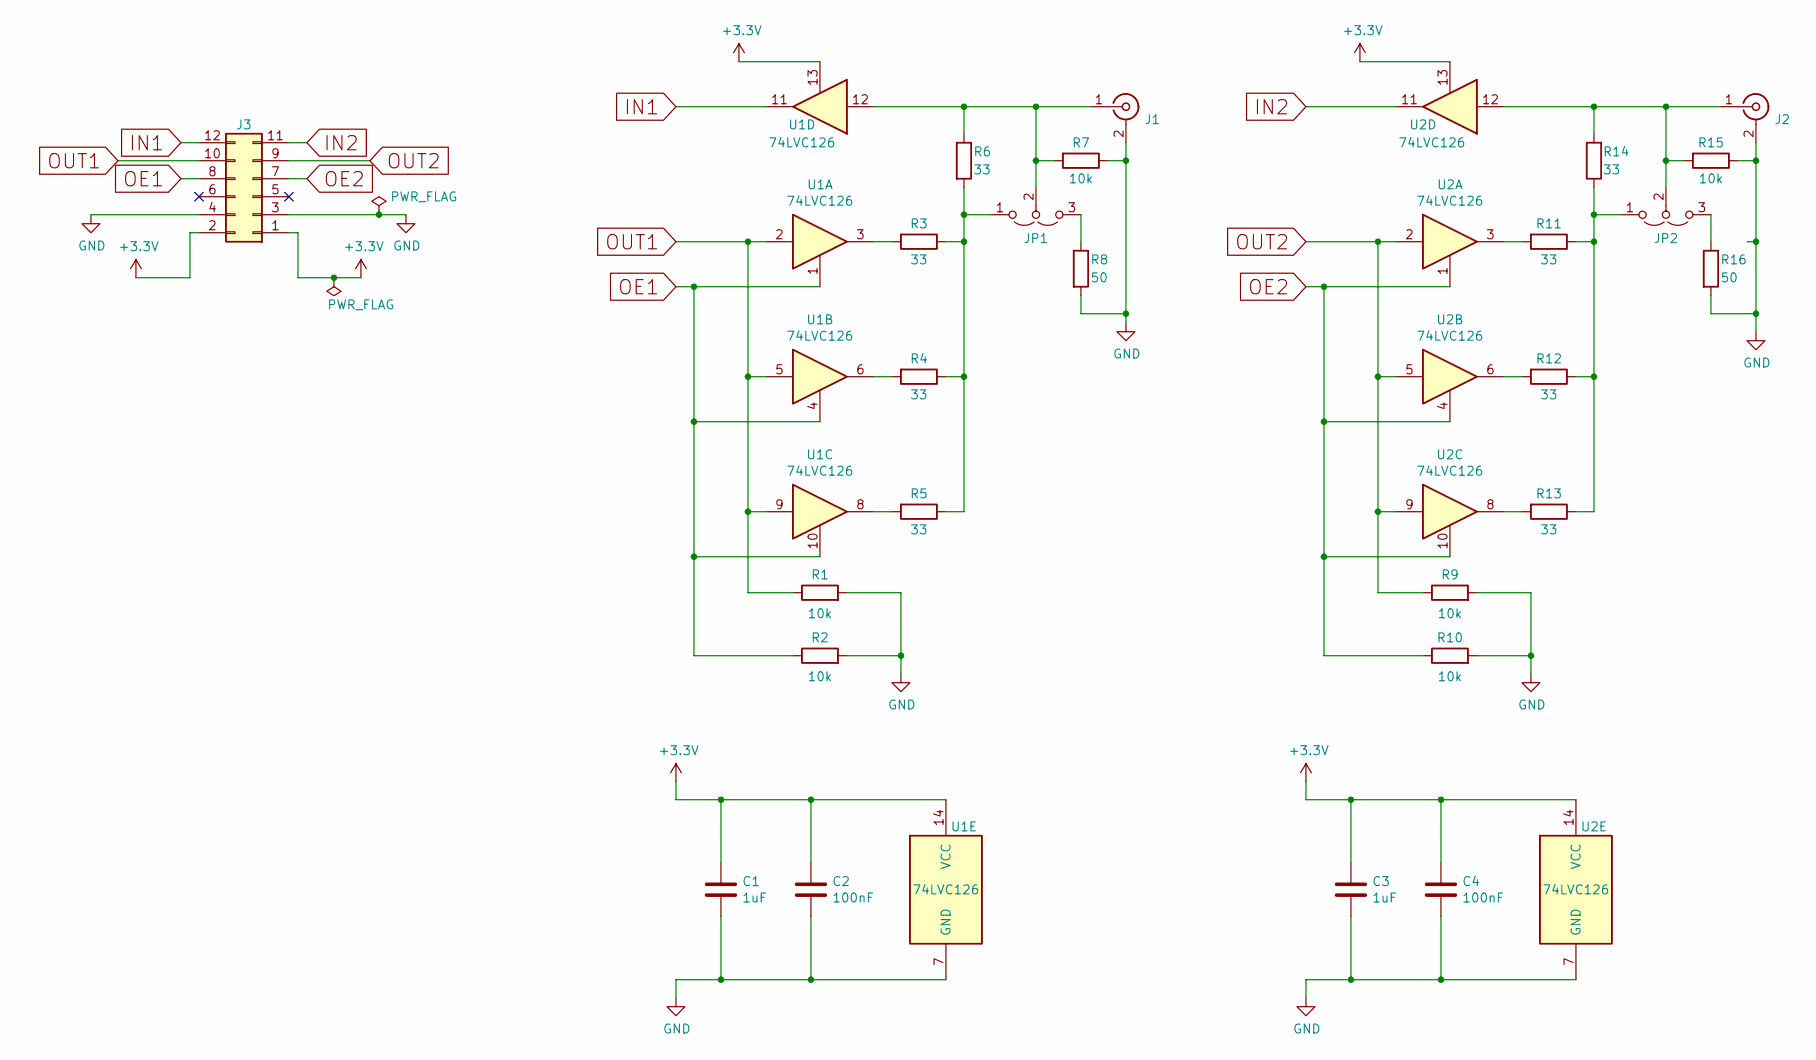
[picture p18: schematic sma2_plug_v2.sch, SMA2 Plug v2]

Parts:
C1, C3: 1uF; C_0805_2012Metric_Pad1.15x1.40mm_HandSolder
C2, C4: 100nF; C_0805_2012Metric_Pad1.15x1.40mm_HandSolder
J1, J2: Conn_Coaxial; SMA_Samtec_SMA-J-P-X-ST-EM1_EdgeMount
J3: Conn_02x06_Top_Bottom; PinHeader_2x06_P2.54mm_Horizontal
JP1, JP2: Jumper_3_Open; PinHeader_1x03_P2.54mm_Vertical
R1, R2, R7, R9, R10, R15: 10k; R_0805_2012Metric_Pad1.15x1.40mm_HandSolder
R3, R4, R5, R6, R11, R12, R13, R14: 33; R_0805_2012Metric_Pad1.15x1.40mm_HandSolder
R8, R16: 50; R_1206_3216Metric_Pad1.42x1.75mm_HandSolder
U1, U2: 74LVC126; SOIC-14_3.9x8.7mm_P1.27mm

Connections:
+3V3: C1.1, C2.1, C3.1, C4.1, J3.1, J3.2, U1.13, U1.14 (VCC), U2.13, U2.14 (VCC)
GND: C1.2, C2.2, C3.2, C4.2, J1.2 (Ext), J2.2 (Ext), J3.3, J3.4, R1.2, R2.2, R7.1, R8.2, R9.2, R10.2, R15.1, R16.2, U1.7 (GND), U2.7 (GND)
IN1: J3.12, U1.11
IN2: J3.11, U2.11
unnamed: J1.1 (In), JP1.2 (C), R6.1, R7.2, U1.12
unnamed: J2.1 (In), JP2.2 (C), R14.2, R15.2, U2.12
unnamed: JP1.1 (A), R3.1, R4.1, R5.1, R6.2
unnamed: JP1.3 (B), R8.1
unnamed: JP2.1 (A), R11.1, R12.1, R13.1, R14.1
unnamed: JP2.3 (B), R16.1
unnamed: R3.2, U1.3
unnamed: R4.2, U1.6
unnamed: R5.2, U1.8
unnamed: R11.2, U2.3
unnamed: R12.2, U2.6
unnamed: R13.2, U2.8
OE1: J3.8, R2.1, U1.1, U1.4, U1.10
OE2: J3.7, R10.1, U2.1, U2.4, U2.10
OUT1: J3.10, R1.1, U1.2, U1.5, U1.9
OUT2: J3.9, R9.1, U2.2, U2.5, U2.9

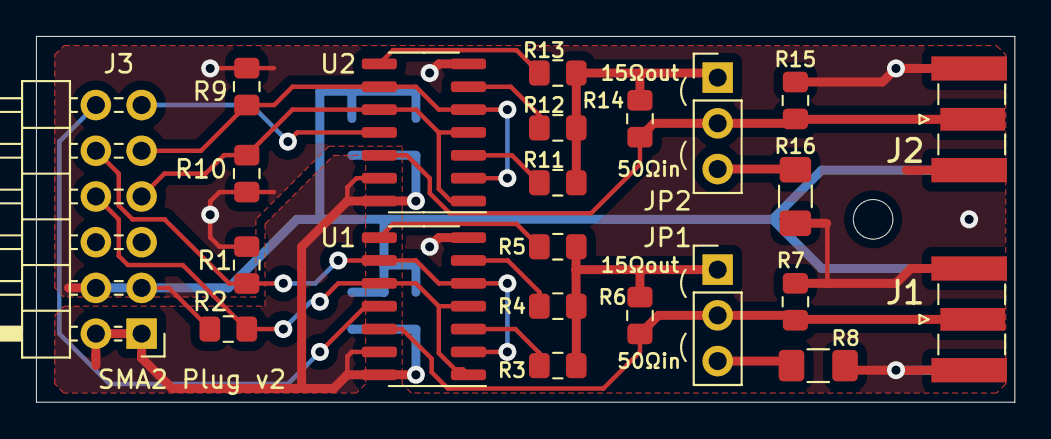
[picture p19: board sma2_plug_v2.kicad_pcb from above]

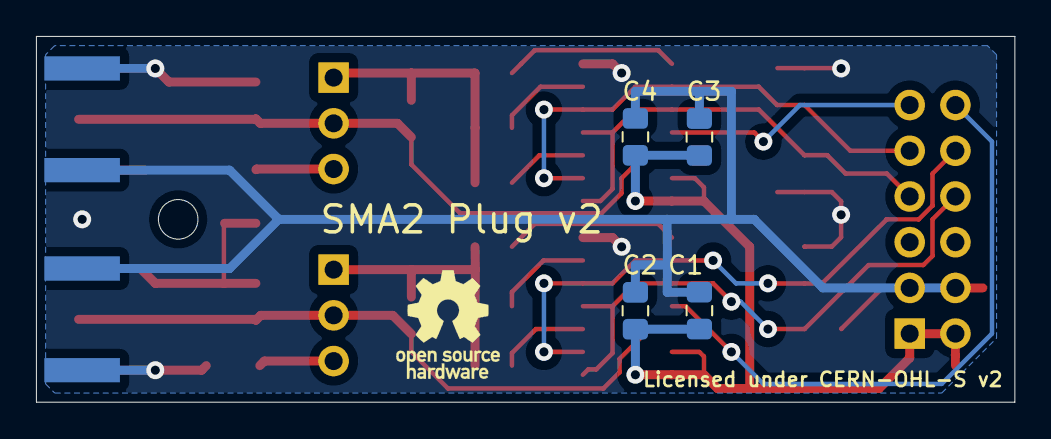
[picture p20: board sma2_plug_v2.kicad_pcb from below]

Board: 2 copper layers, 54.4 x 20.3 mm, 27 parts (4 on the bottom side), 20 nets.

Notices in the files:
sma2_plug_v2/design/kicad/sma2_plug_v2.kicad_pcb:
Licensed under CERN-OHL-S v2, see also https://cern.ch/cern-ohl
